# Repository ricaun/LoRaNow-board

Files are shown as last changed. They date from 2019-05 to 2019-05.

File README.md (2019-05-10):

# LoRaNow Board

LoRaNow Boards is a project with open source hardware using the Arduino (atmega328p) and LoRa Module (RFM95).

This boards were designed to work with [LoRaNow Library][3].

## LoRaNow v0

<a href="v0">
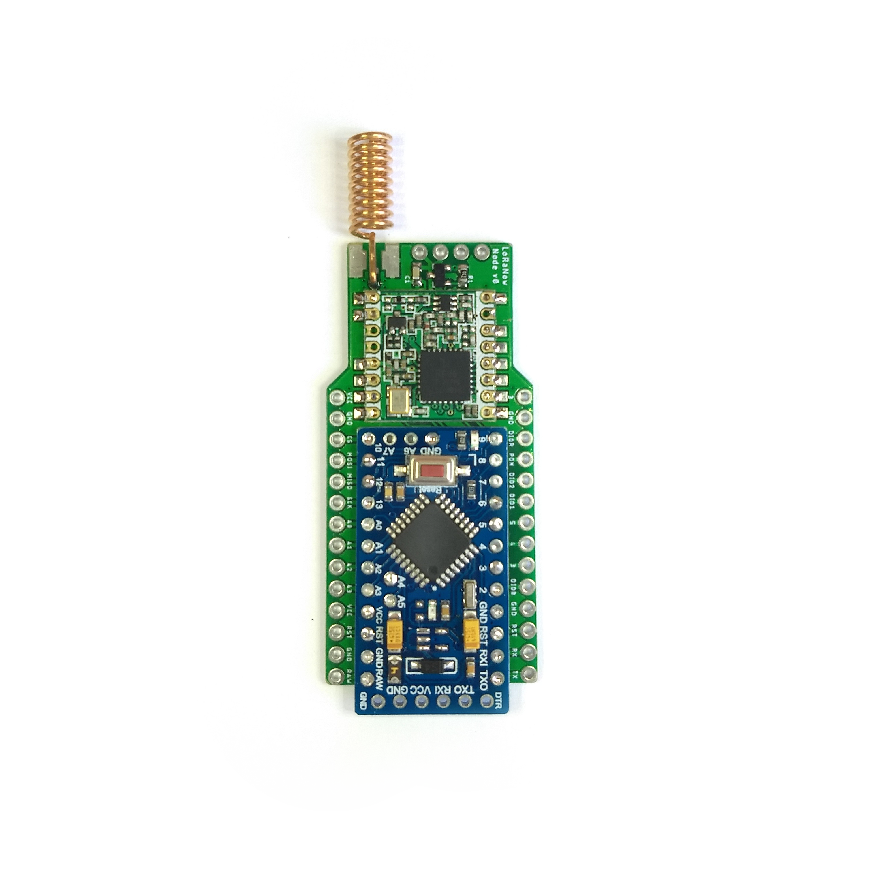
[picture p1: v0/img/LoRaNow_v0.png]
LoRaNow_v0

</a>

## LoRaNow v1

<a href="v1">
LoRaNow_v1
</a>

## License

<br />This work is licensed under a <a rel="license" href="http://creativecommons.org/licenses/by-nc-sa/4.0/">Creative Commons Attribution-NonCommercial-ShareAlike 4.0 International License</a>.

If you want to do commercial stuff with this project, please contact [ricaun][1] so we can organize an simple agreement.

## Blog

See news and other projects on my [blog][2] 

[1]: http://www.ricaun.com.br/#contact
[2]: http://www.loranow.com
[3]: https://github.com/ricaun/LoRaNow

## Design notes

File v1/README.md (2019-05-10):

# LoRaNow v1

LoRaNow Boards v1 is a PCB to help wiring between Atmega328p and RFM95 LoRa module to work with 2 AA batteries.

LoRaNow_v1

## Detailed Description

This board has:
* Footprint for Atmega328p
* Footprint for RFM95
* Footprint for P-Channel Mosfet to turn on/off the RFM95
* Classic I2C connector (VCC, GND, SCL, SDA)
* Footprint for Diodes (DIO0/DIO1/DIO2 to pin 2)
* Footprint for Ultra Low Power controller TPL5110 (Optional)

Look at the schematics for more informations.

Pins board connections.
```
  Arduino       RFM9x Module
  13 <--------> CLK
  12 <--------> MISO
  11 <--------> MOSI
  10 <--------> CS
  9  <--------> P-MOSFET
  2  <-DIODES-> DIO0/DIO1/DIO2
```

## Schematic

LoRaNow_v1s

## Boards

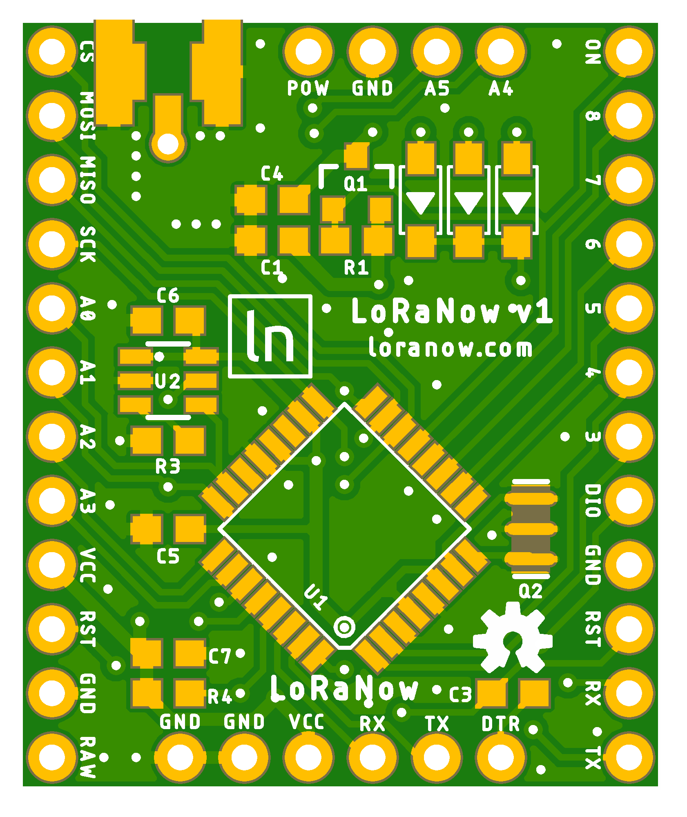
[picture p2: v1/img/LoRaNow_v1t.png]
LoRaNow_v1t
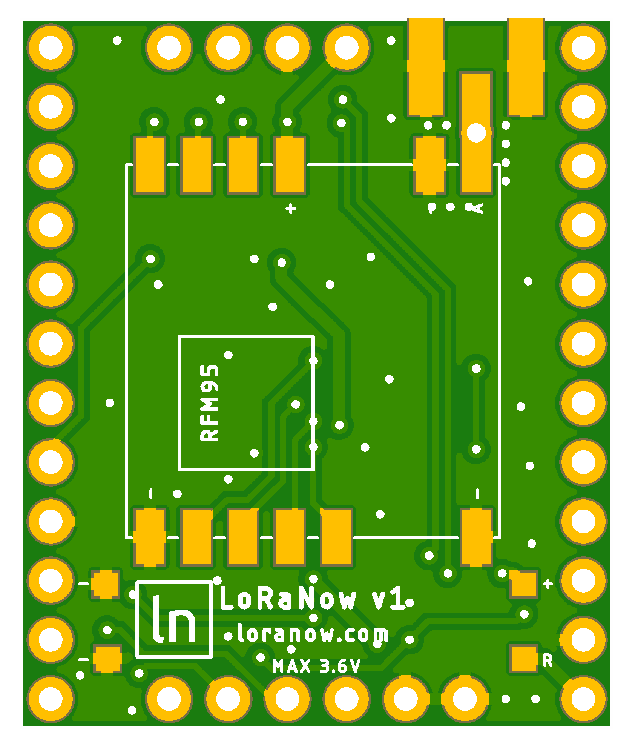
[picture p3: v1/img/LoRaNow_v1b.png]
LoRaNow_v1b


## Bill Of Material

* Atmega328p (SMD)
* 8MHz cystal (SMD)
* RFM95 (check Frequency)
* Resistor 10k (603) (x2)
* Capacitor 1u (603)
* Capacitor 0.1u (603) (x5)
* P-Channel Mosfet (SOT23)
* 1N4148 (SOD123) (x3)
* Ultra Low Power controller TPL5110
* Resistor 124k (603)
* Battery holder (2xAA)
* Antenna 

## License

<br />This work is licensed under a <a rel="license" href="http://creativecommons.org/licenses/by-nc-sa/4.0/">Creative Commons Attribution-NonCommercial-ShareAlike 4.0 International License</a>.

If you want to do commercial stuff with this project, please contact [ricaun][1] so we can organize an simple agreement.

## Blog

See news and other projects on my [blog][2] 

[1]: http://www.ricaun.com.br/#contact
[2]: http://www.loranow.com

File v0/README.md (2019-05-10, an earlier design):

# LoRaNow v0

LoRaNow Boards v0 is a PCB to help wiring between Arduino Mini and RFM95 LoRa module to work with 2 AA batteries.

LoRaNow_v0

## Detailed Description

This board has:
* Footprint for Arduino Pro Mini
* Footprint for RFM95
* Footprint for P-Channel Mosfet to turn on/off the RFM95
* Classic I2C connector (VCC, GND, SCL, SDA)
* Jumper to DIO1/DIO2/RST for RFM95
* Jumper to VCC the P-Channel Mosfet

Look at the schematics for more informations.

Pins board connections.
```
  Arduino       RFM9x Module
  13 <--------> CLK
  12 <--------> MISO
  11 <--------> MOSI
  10 <--------> CS
  9  <--DRST--> RST
  8  <--------> P-MOSFET
  7  <--DIO2--> DIO2
  6  <--DIO1--> DIO1
  2  <--------> DIO0
```

## Schematic

LoRaNow_v0s

## Boards

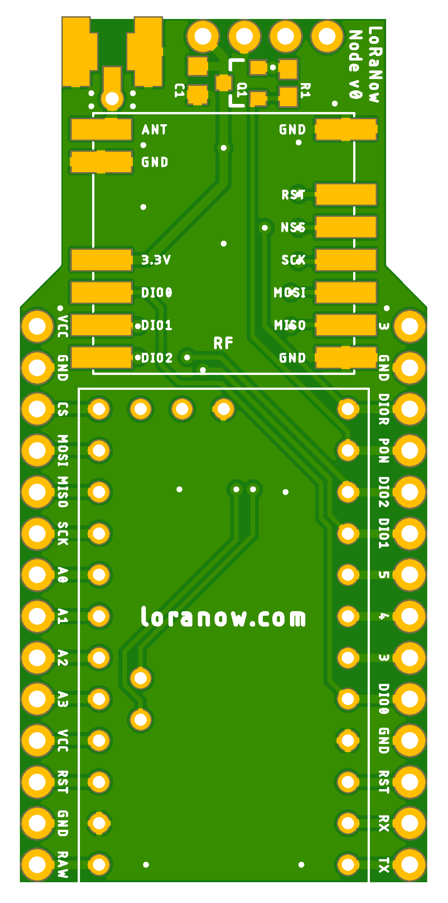
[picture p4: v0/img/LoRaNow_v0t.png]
LoRaNow_v0t
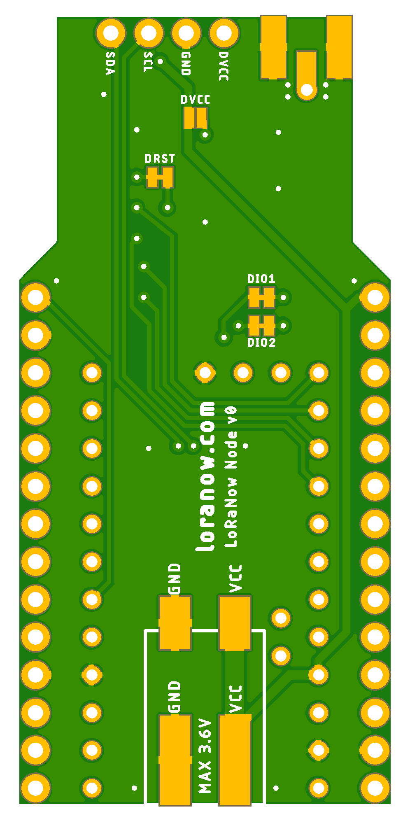
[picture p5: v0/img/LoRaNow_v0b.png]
LoRaNow_v0b


## Bill Of Material

* Arduino Pro Mini (8MHz)
* RFM95 (check Frequency)
* Capacitor 0.1u (603) (Optional)
* P-Channel Mosfet (SOT23) (Optional) 
* Resistor 10k (603) (Optional)
* Battery holder (2xAA)
* Antenna

## License

<br />This work is licensed under a <a rel="license" href="http://creativecommons.org/licenses/by-nc-sa/4.0/">Creative Commons Attribution-NonCommercial-ShareAlike 4.0 International License</a>.

If you want to do commercial stuff with this project, please contact [ricaun][1] so we can organize an simple agreement.

## Blog

See news and other projects on my [blog][2] 

[1]: http://www.ricaun.com.br/#contact
[2]: http://www.loranow.com

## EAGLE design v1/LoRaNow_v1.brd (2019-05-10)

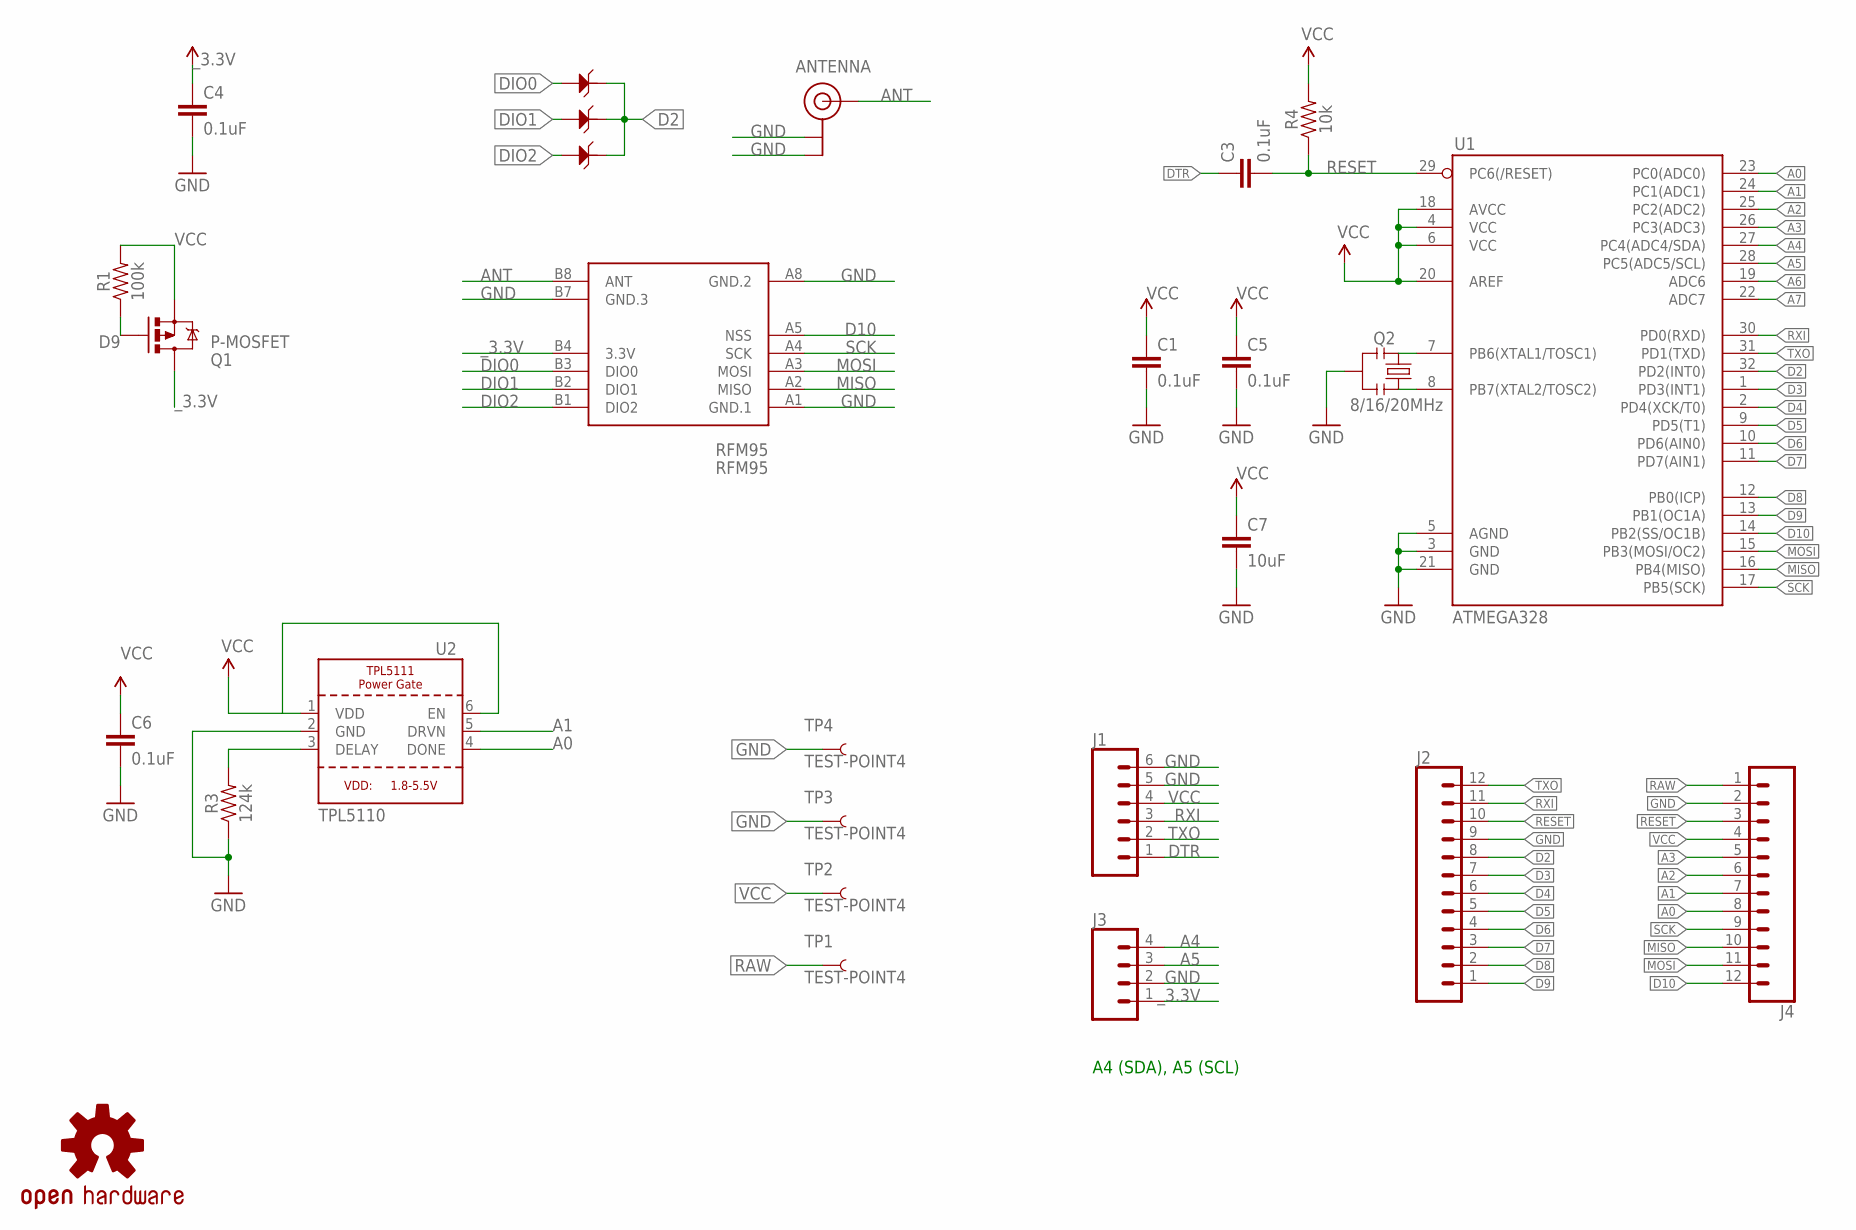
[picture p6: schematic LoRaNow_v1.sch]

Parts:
ANTENNA: U.FLU.FL_2A; U.FL_2A
C1, C3, C4, C5, C6: 0.1uF; 0603
C7: 10uF; 0603
D2, D3, D4: 1N4148; SOD123-2.7X1.6
J1: CONN_06NO_SILK_FEMALE_PTH; 1X06_NO_SILK
J2, J4: CONN_12NO_SILK; 1X12_NO_SILK
J3: CONN_041X04_NO_SILK; 1X04_NO_SILK
Q1: P-MOSFET; SOT23-3
Q2: 8/16/20MHz; RESONATOR-SMD-1:1
R1: 100k; 0603
R3: 124k; 0603
R4: 10k; 0603
RFM95: RFM95; WIRELESS-LORANOW-RFM95W#SMD#2
TP1, TP2, TP3, TP4: TEST-POINT4; PAD.02X.04
U1: ATMEGA328; TQFP32-08
U2: TPL5110; SOT23-6
U$3: OSHW-LOGOS; OSHW-LOGO-S

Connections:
A0: J4.8, U1.23 (PC0(ADC0)), U2.4 (DONE)
A1: J4.7, U1.24 (PC1(ADC1)), U2.5 (DRVN)
A2: J4.6, U1.25 (PC2(ADC2))
A3: J4.5, U1.26 (PC3(ADC3))
A4: J3.4, U1.27 (PC4(ADC4/SDA))
A5: J3.3, U1.28 (PC5(ADC5/SCL))
A6: U1.19 (ADC6)
A7: U1.22 (ADC7)
ANT: ANTENNA.FEED (SIGNAL), ANTENNA.FEED.B (SIGNAL), ANTENNA.FEED.P (SIGNAL), RFM95.B8 (ANT)
D2: D2.2, D3.2, D4.2, J2.8, U1.32 (PD2(INT0))
D3: J2.7, U1.1 (PD3(INT1))
D4: J2.6, U1.2 (PD4(XCK/T0))
D5: J2.5, U1.9 (PD5(T1))
D6: J2.4, U1.10 (PD6(AIN0))
D7: J2.3, U1.11 (PD7(AIN1))
D8: J2.2, U1.12 (PB0(ICP))
D9: J2.1, Q1.1 (G), R1.1, U1.13 (PB1(OC1A))
D10: J4.12, RFM95.A5 (NSS), U1.14 (PB2(SS/OC1B))
DELAY: R3.2, U2.3 (DELAY)
DIO0: D2.1, RFM95.B3 (DIO0)
DIO1: D3.1, RFM95.B2 (DIO1)
DIO2: D4.1, RFM95.B1 (DIO2)
DTR: C3.1, J1.1
GND: ANTENNA.1 (GND), ANTENNA.2 (GND), ANTENNA.3 (GND), ANTENNA.4 (GND), ANTENNA.5 (GND), ANTENNA.6 (GND), C1.2, C4.2, C5.2, C6.2, C7.2, J1.5, J1.6, J2.9, J3.2, J4.2, Q2.2, R3.1, RFM95.A1 (GND.1), RFM95.A8 (GND.2), RFM95.B7 (GND.3), TP3.P$1, TP4.P$1, U1.3 (GND), U1.5 (AGND), U1.21 (GND), U2.2 (GND)
MISO: J4.10, RFM95.A2 (MISO), U1.16 (PB4(MISO))
MOSI: J4.11, RFM95.A3 (MOSI), U1.15 (PB3(MOSI/OC2))
RAW: J4.1, TP1.P$1
RESET: C3.2, J2.10, J4.3, R4.1, U1.29 (PC6(/RESET))
RXI: J1.3, J2.11, U1.30 (PD0(RXD))
SCK: J4.9, RFM95.A4 (SCK), U1.17 (PB5(SCK))
TXO: J1.2, J2.12, U1.31 (PD1(TXD))
VCC: C1.1, C5.1, C6.1, C7.1, J1.4, J4.4, Q1.2 (S), R1.2, R4.2, TP2.P$1, U1.4 (VCC), U1.6 (VCC), U1.18 (AVCC), U1.20 (AREF), U2.1 (VDD), U2.6 (EN)
X1: Q2.1, U1.7 (PB6(XTAL1/TOSC1))
X2: Q2.3, U1.8 (PB7(XTAL2/TOSC2))
_3.3V: C4.1, J3.1, Q1.3 (D), RFM95.B4 (3.3V)

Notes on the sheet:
A4 (SDA), A5 (SCL)

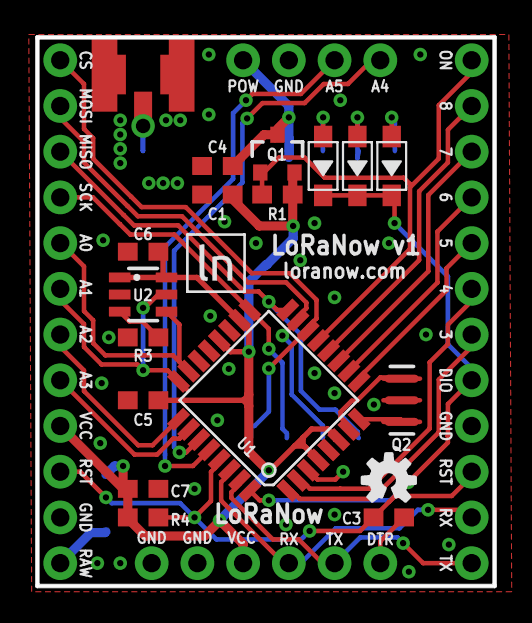
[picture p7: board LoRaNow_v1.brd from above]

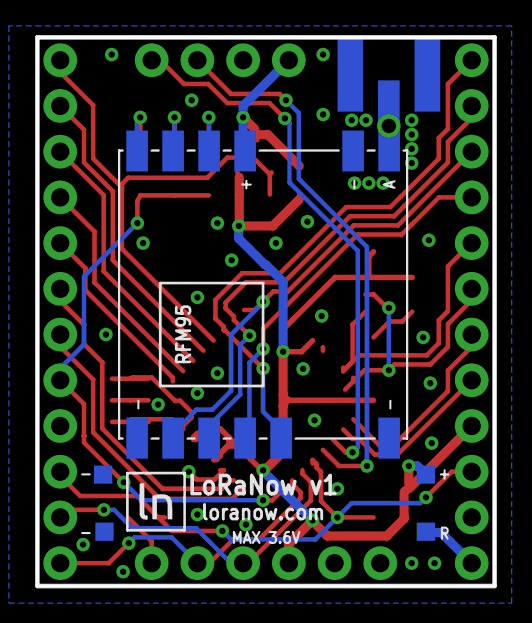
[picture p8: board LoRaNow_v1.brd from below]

Board: 2 copper layers, 25.4 x 30.5 mm, 29 parts (6 on the bottom side), 33 nets.

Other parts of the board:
U$7, U$8: LORANOW_SMALL_BOX

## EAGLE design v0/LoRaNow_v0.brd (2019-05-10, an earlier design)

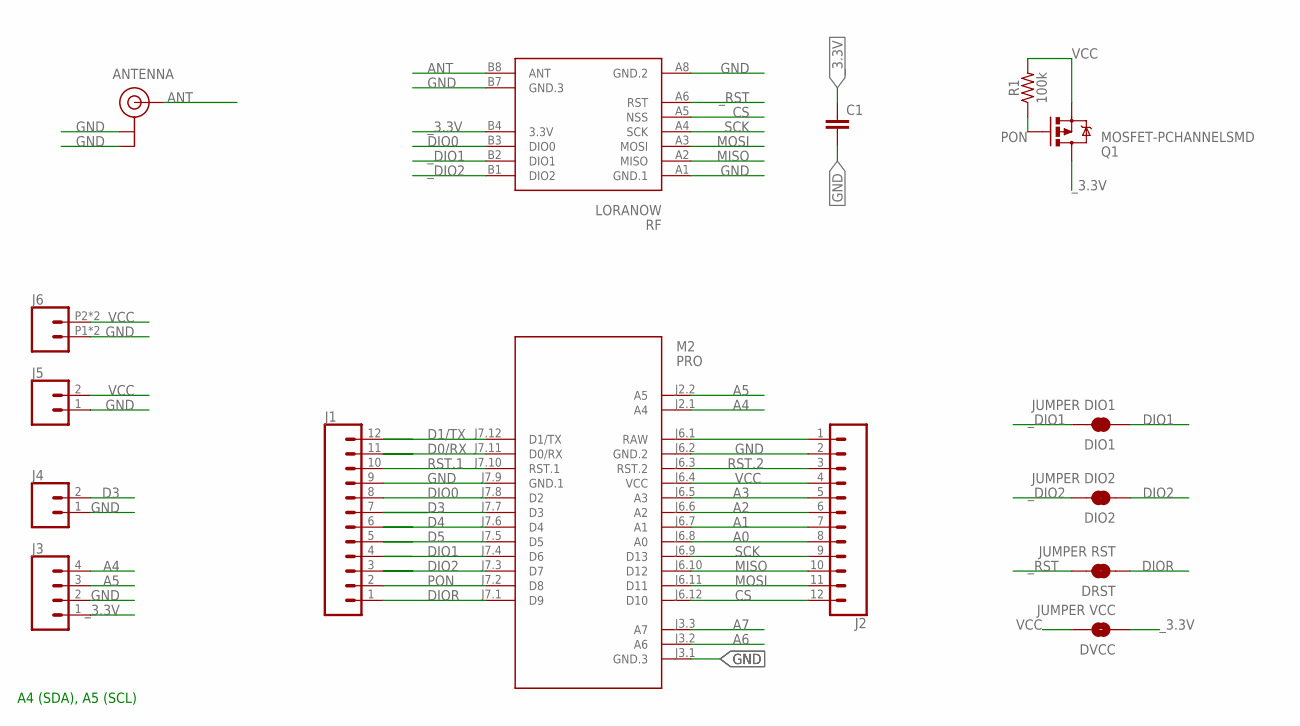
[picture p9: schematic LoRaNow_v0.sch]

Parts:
ANTENNA: U.FLU.FL2; U.FL_2
C1: C-EUC0603K; C0603K
DIO1: JUMPER DIO1; SMT-JUMPER_2_NC_TRACE_NO-SILK
DIO2: JUMPER DIO2; SMT-JUMPER_2_NC_TRACE_NO-SILK
DRST: JUMPER RST; SMT-JUMPER_2_NC_TRACE_NO-SILK
DVCC: JUMPER VCC; SMT-JUMPER_2_NO_NO-SILK
J1, J2: CONN_12NO_SILK; 1X12_NO_SILK
J3: CONN_041X04_NO_SILK; 1X04_NO_SILK
J4, J5: CONN_021X02_NO_SILK; 1X02_NO_SILK
J6: CONN_02SMALL_POKEHOME; 1X02_POKEHOME
M2: PRO; ARDUINO-PRO-MINI#NP#2
Q1: MOSFET-PCHANNELSMD; SOT23-3
R1: 100k; 0603
RF: LORANOW; WIRELESS-LORA-RFM95W#SMD#2

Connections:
A0: J2.8, M2.J6.8 (A0)
A1: J2.7, M2.J6.7 (A1)
A2: J2.6, M2.J6.6 (A2)
A3: J2.5, M2.J6.5 (A3)
A4: J3.4, M2.J2.1 (A4)
A5: J3.3, M2.J2.2 (A5)
A6: M2.J3.2 (A6)
A7: M2.J3.3 (A7)
ANT: ANTENNA.FEED (SIGNAL), ANTENNA.FEED.P (SIGNAL), RF.B8 (ANT)
CS: J2.12, M2.J6.12 (D10), RF.A5 (NSS)
D0/RX: J1.11, M2.J7.11 (D0/RX)
D1/TX: J1.12, M2.J7.12 (D1/TX)
D3: J1.7, J4.2, M2.J7.7 (D3)
D4: J1.6, M2.J7.6 (D4)
D5: J1.5, M2.J7.5 (D5)
DIO0: J1.8, M2.J7.8 (D2), RF.B3 (DIO0)
DIO1: DIO1.1, J1.4, M2.J7.4 (D6)
DIO2: DIO2.1, J1.3, M2.J7.3 (D7)
DIOR: DRST.1, J1.1, M2.J7.1 (D9)
GND: ANTENNA.1 (GND), ANTENNA.2 (GND), ANTENNA.3 (GND), ANTENNA.4 (GND), ANTENNA.5 (GND), ANTENNA.6 (GND), C1.2, J1.9, J2.2, J3.2, J4.1, J5.1, J6.P1 (1), J6.P3 (1), M2.J3.1 (GND.3), M2.J6.2 (GND.2), M2.J7.9 (GND.1), RF.A1 (GND.1), RF.A8 (GND.2), RF.B7 (GND.3)
MISO: J2.10, M2.J6.10 (D12), RF.A2 (MISO)
MOSI: J2.11, M2.J6.11 (D11), RF.A3 (MOSI)
PON: J1.2, M2.J7.2 (D8), Q1.1 (G), R1.1
RAW: J2.1, M2.J6.1 (RAW)
RST.1: J1.10, M2.J7.10 (RST.1)
RST.2: J2.3, M2.J6.3 (RST.2)
SCK: J2.9, M2.J6.9 (D13), RF.A4 (SCK)
VCC: DVCC.2, J2.4, J5.2, J6.P2 (2), J6.P4 (2), M2.J6.4 (VCC), Q1.2 (S), R1.2
_3.3V: C1.1, DVCC.1, J3.1, Q1.3 (D), RF.B4 (3.3V)
_DIO1: DIO1.2, RF.B2 (DIO1)
_DIO2: DIO2.2, RF.B1 (DIO2)
_RST: DRST.2, RF.A6 (RST)

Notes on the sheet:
A4 (SDA), A5 (SCL)

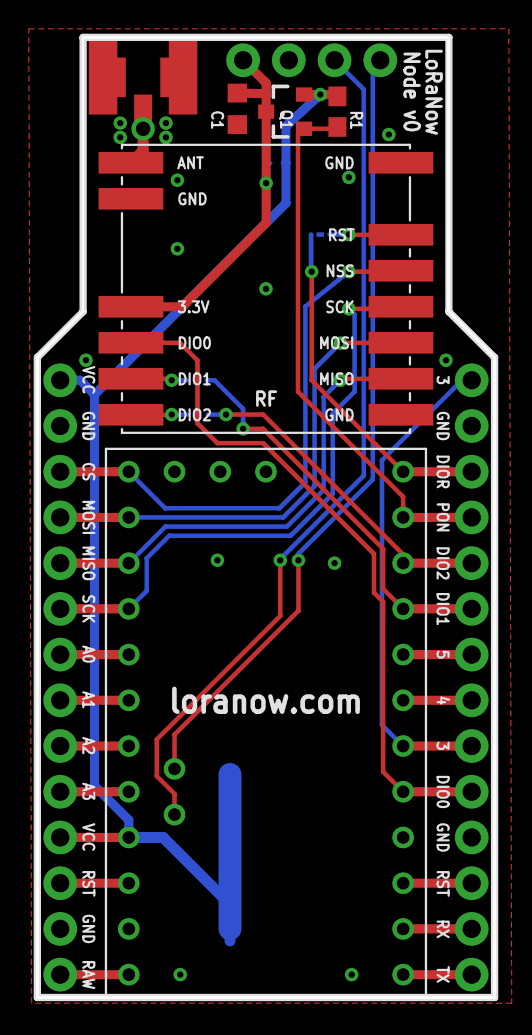
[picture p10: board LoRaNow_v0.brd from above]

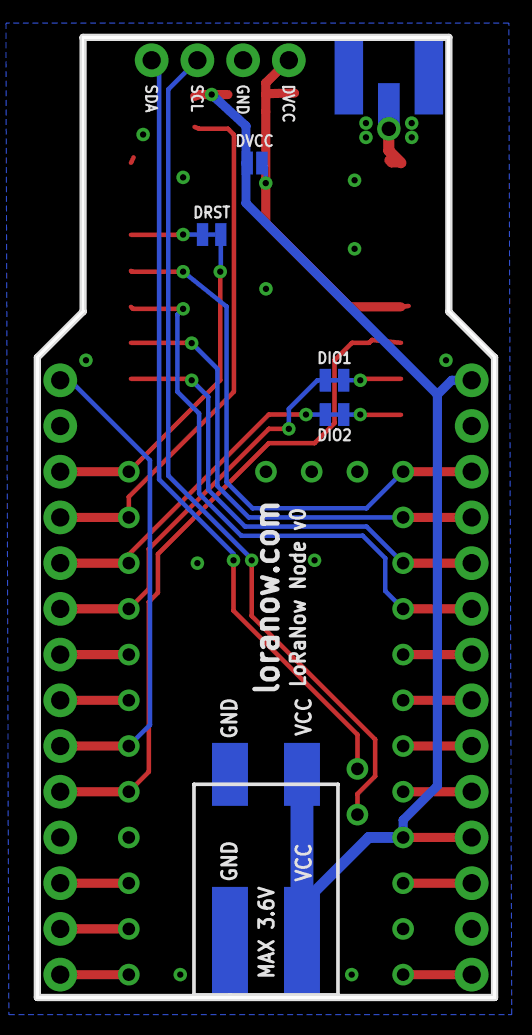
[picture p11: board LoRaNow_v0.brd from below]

Board: 2 copper layers, 25.4 x 53.3 mm, 16 parts (5 on the bottom side), 30 nets.

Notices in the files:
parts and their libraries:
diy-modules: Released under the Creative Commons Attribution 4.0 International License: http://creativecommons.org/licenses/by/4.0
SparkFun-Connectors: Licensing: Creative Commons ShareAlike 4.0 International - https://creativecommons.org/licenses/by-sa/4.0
